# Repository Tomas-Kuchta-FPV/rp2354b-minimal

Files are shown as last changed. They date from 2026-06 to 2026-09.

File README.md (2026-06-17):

# RP2354B Minimal for KiCad 10

This is a realization of the Raspberry Pi RP2350 "Minimal" design.

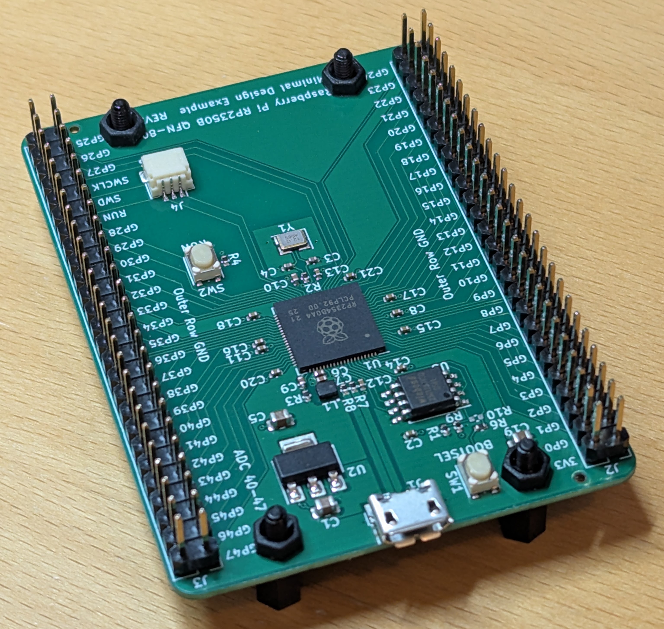
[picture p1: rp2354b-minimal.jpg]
Picture of Board


My main objectives were to try the RP2354 for the internal flash and use the
"B" part for the extra GPIOs.

Going through
[Hardware design with RP2350](https://pip-assets.raspberrypi.com/categories/1214-rp2350/documents/RP-008280-DS-1-hardware-design-with-rp2350.pdf)
is required to do this stuff and expect good results. It has a link to the
original Kicad 7.0 version.

Changes from the original example:

* Kicad 10.0.3 (was Kicad 7.0). This just means opening the project with
  10.0.3 and immediately saving it.

* RP2354 (was RP2350). This means changing some of the components from
  do-not-populate to populate, and vice versa.

* Added JLCPCB part numbers. There are lots of options for most parts, and I
  just picked ones in stock.

Then I created the manufacturing output for JLCPCB, uploaded the files, and a
week later got apparently-working boards. "Apparently" in that the board I've
tried shows up as a usb drive (Windows) if I hold BOOTSEL, the debugger
(Raspberry Pi debugger under VS Code) connects and can load code, the board
tells me it's running at 150 MHz, and I can blink LEDs after soldering on
headers. I have not tried using the secondary flash, just the internal flash.
The boards look nicely done, including getting the inductors turned the right
way on all five boards I got.

One objective was to change as little as possible, partly because I have not
done any boards with JLCPCB using 0402 and such tiny traces, and would be
unlikely to be able debug it if something didn't work, i.e. the oscillator or
power supply. But they must be fine.

I told VS Code it's a pico-2 to connect to it, so some stuff is probably wrong
(like flash size).

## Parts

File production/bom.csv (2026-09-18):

Designator | Footprint | Quantity | Value | LCSC Part #
C1, C19, C5 | 0805 | 3 | 10u | C15850
C10, C6, C7, C9 | 0402 | 4 | 4.7u | C368809
C11, C12, C13, C14, C15, C16, C17, C18, C2, C20, C21, C8 | 0402 | 12 | 100n | C16193311
C3, C4 | 0402 | 2 | 15p | C307341
J4 | JST_SH_SM03B-SRSS-TB_1x03-1MP_P1.00mm_Horizontal | 1 | SM03B-SRSS-TB | C160403
J5 | USB_C_Receptacle_HRO_TYPE-C-31-M-12 | 1 | USB_C_Receptacle_USB2.0_16P | C165948
L1 | L_pol_2016 | 1 | 3.3u | C42411119
R1 | 0402 | 1 | 10k | C25744
R12, R5 | 0805 | 2 | 5k1 | C84375
R2, R4, R6 | 0402 | 3 | 1k | C11702
R3 | 0402 | 1 | 33 | C25105
R7, R8 | 0402 | 2 | 27 | C138021
R9 | 0402 | 1 | 0 | C17168
SW1, SW2 | SW_Push_1P1T_NO_Vertical_Wuerth_434133025816 | 2 | SW_Push | C115360
U1 | RP2350-QFN-80-1EP_10x10_P0.4mm_EP3.4x3.4mm_ThermalVias | 1 | RP2350_80QFN | C39843328
U2 | SOT-223-3_TabPin2 | 1 | NCP1117-3.3_SOT223 | C26537
U3 | SOIC-8_5.23x5.23mm_P1.27mm | 1 | W25Q128JVS | C97521
U5 | SOT-23-6 | 1 | USBLC6-2SC6 | C2827654
Y1 | Crystal_SMD_3225-4Pin_3.2x2.5mm | 1 | ABM8-272-T3 | C20625731

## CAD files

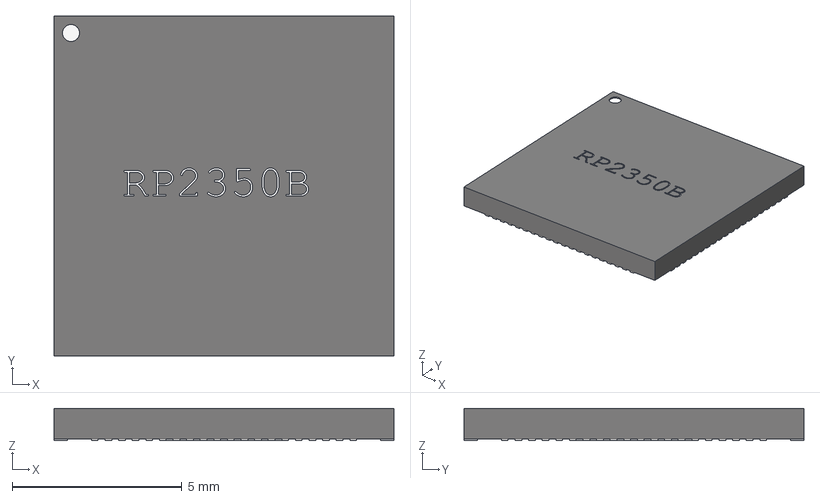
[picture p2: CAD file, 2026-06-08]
RP2350_QFN80.step
10.0 x 10.0 x 0.95 mm

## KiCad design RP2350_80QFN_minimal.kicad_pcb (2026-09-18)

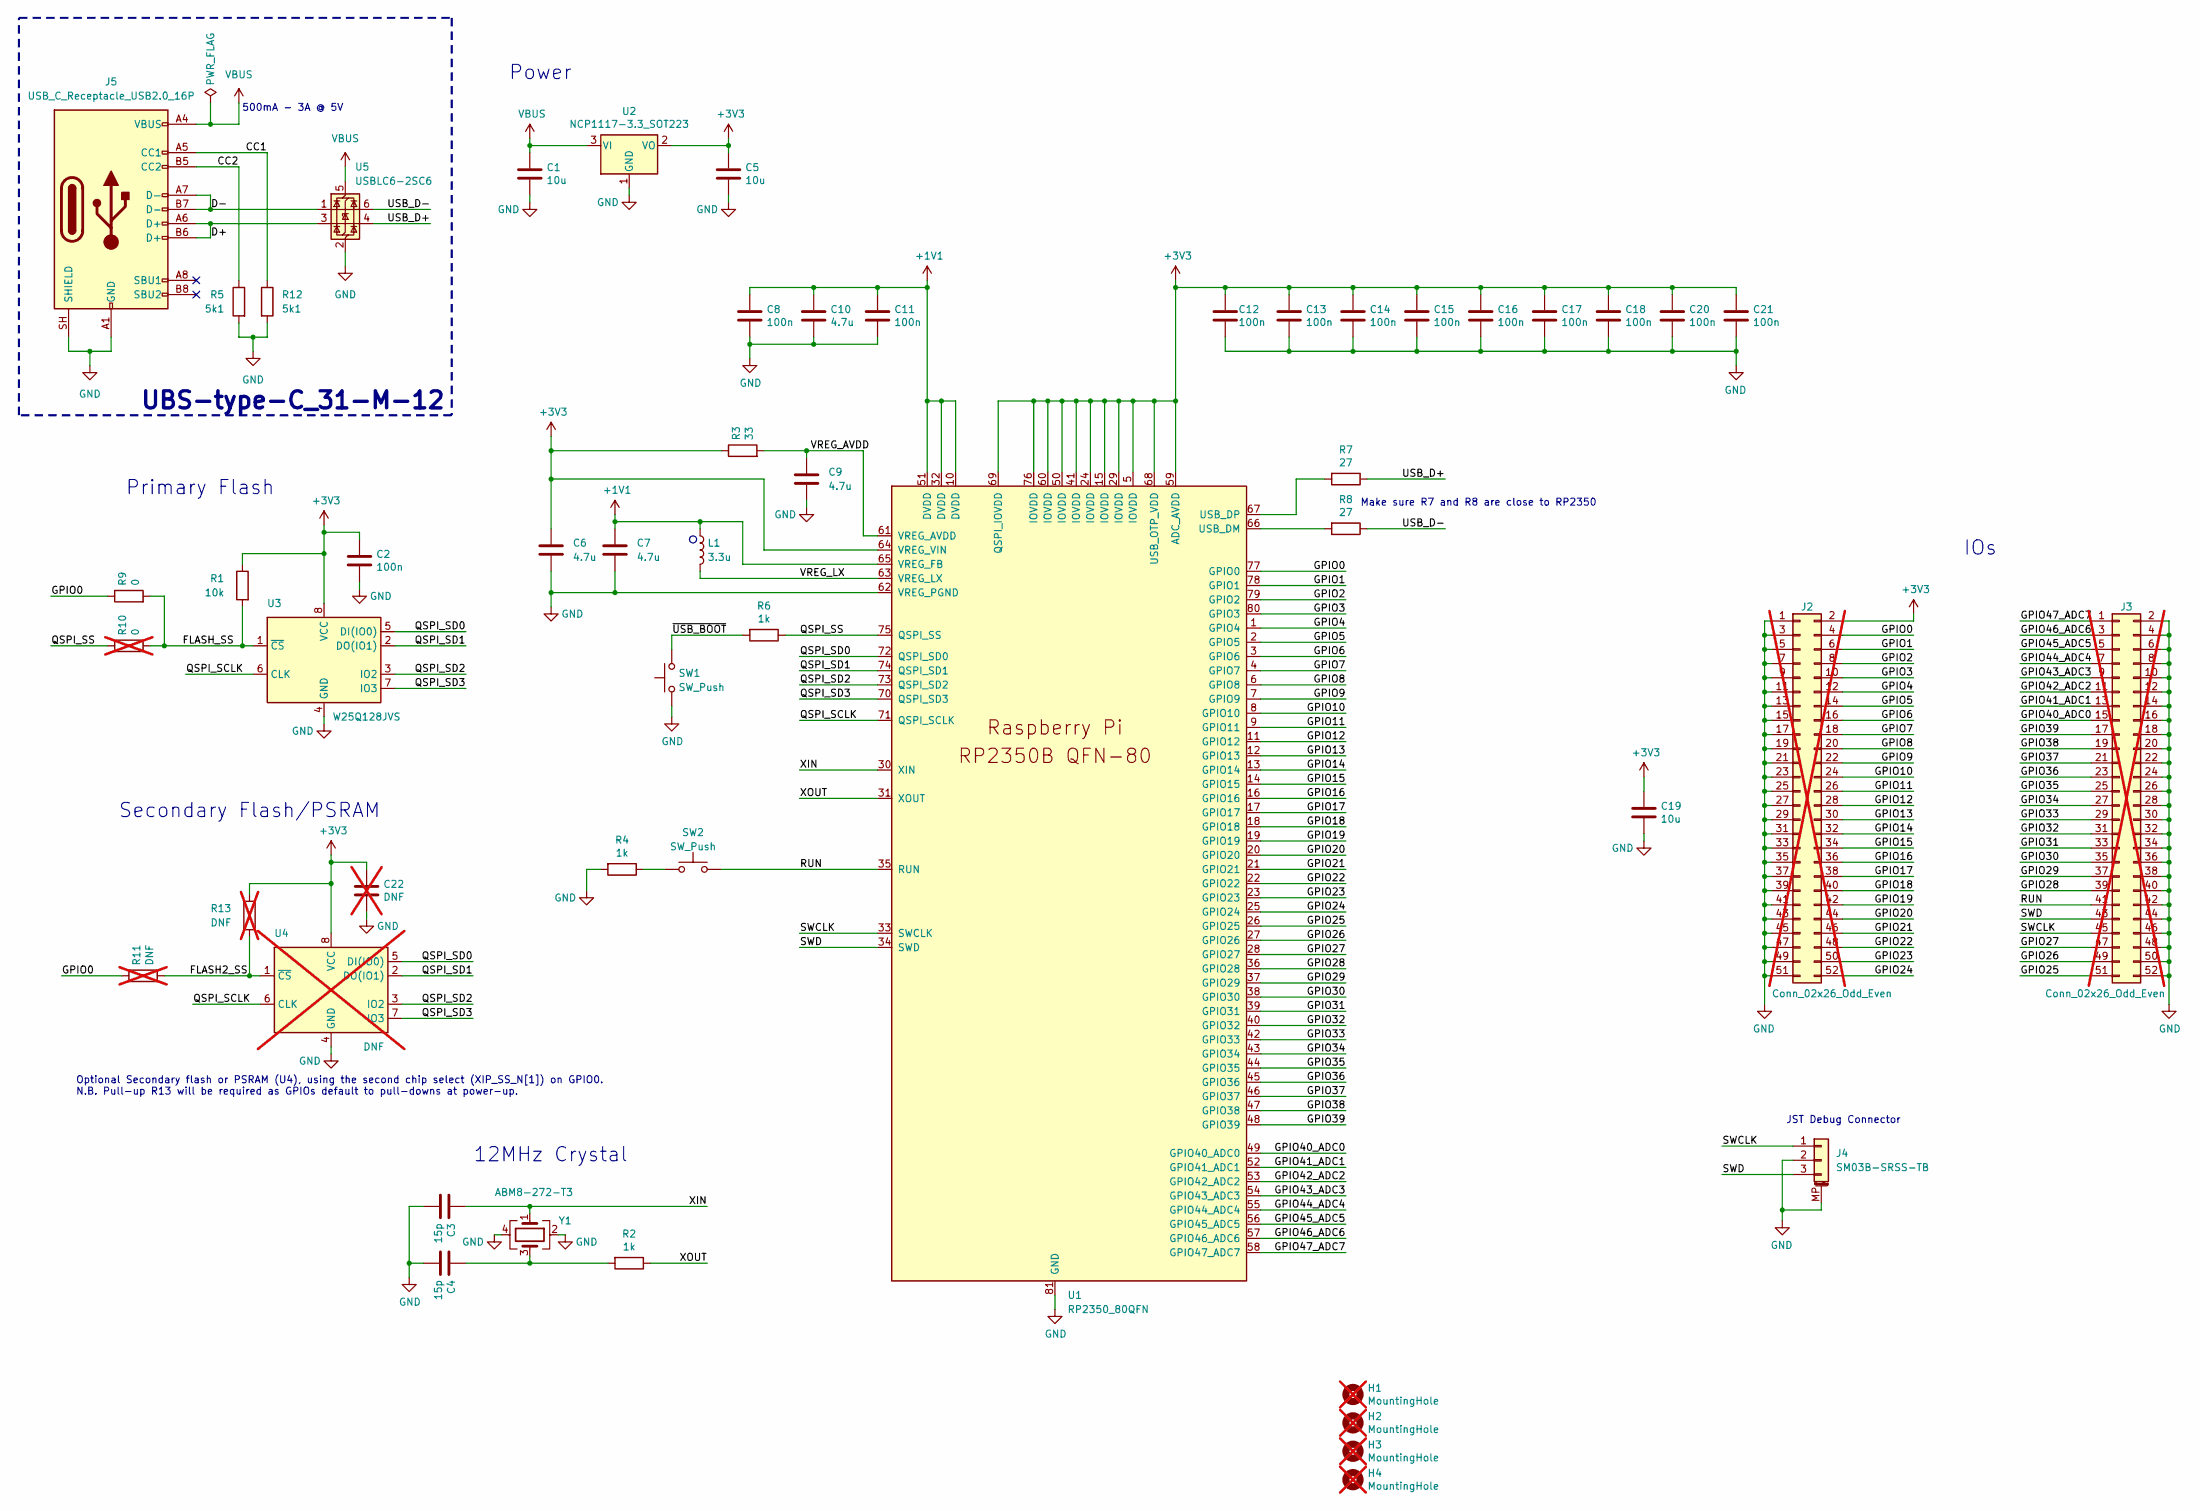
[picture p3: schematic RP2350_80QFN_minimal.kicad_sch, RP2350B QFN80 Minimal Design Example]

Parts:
C1, C5, C19: 10u; C_0805_2012Metric; LCSC PN C15850
C2, C8, C11, C12, C13, C14, C15, C16, C17, C18, C20, C21: 100n; C_0402_1005Metric; LCSC PN C16193311
C3, C4: 15p; C_0402_1005Metric; LCSC PN C307341
C6, C7: 4.7u; C_0402_1005Metric_small_pads; LCSC PN C368809
C9, C10: 4.7u; C_0402_1005Metric; LCSC PN C368809
C22: DNF; C_0402_1005Metric; not fitted
H1, H2, H3, H4: MountingHole; MountingHole_2.7mm_M2.5; not fitted
J2, J3: Conn_02x26_Odd_Even; PinHeader_2x26_P2.54mm_Vertical; not fitted
J4: SM03B-SRSS-TB; JST_SH_SM03B-SRSS-TB_1x03-1MP_P1.00mm_Horizontal; LCSC PN C160403
J5: USB_C_Receptacle_USB2.0_16P; USB_C_Receptacle_HRO_TYPE-C-31-M-12; LCSC C165948
L1: 3.3u; L_pol_2016; LCSC PN C42411119
R1: 10k; R_0402_1005Metric; LCSC PN C25744
R2, R4, R6: 1k; R_0402_1005Metric; LCSC PN C11702
R3: 33; R_0402_1005Metric; LCSC PN C25105
R5, R12: 5k1; R_0805_2012Metric_Pad1.20x1.40mm_HandSolder; LCSC C84375
R7, R8: 27; R_0402_1005Metric; LCSC PN C138021
R9: 0; R_0402_1005Metric; LCSC PN C17168
R10: 0; R_0402_1005Metric; not fitted
R11, R13: DNF; R_0402_1005Metric; not fitted
SW1, SW2: SW_Push; SW_Push_1P1T_NO_Vertical_Wuerth_434133025816; LCSC PN C115360
U1: RP2350_80QFN; RP2350-QFN-80-1EP_10x10_P0.4mm_EP3.4x3.4mm_ThermalVias; LCSC PN C39843328
U2: NCP1117-3.3_SOT223; SOT-223-3_TabPin2; LCSC PN C26537
U3: W25Q128JVS; SOIC-8_5.23x5.23mm_P1.27mm; LCSC PN C97521
U4: DNF; SOIC-8_5.23x5.23mm_P1.27mm; not fitted
U5: USBLC6-2SC6; SOT-23-6; LCSC C2827654
Y1: ABM8-272-T3; Crystal_SMD_3225-4Pin_3.2x2.5mm; LCSC PN C20625731

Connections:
+1V1: C7.1, C8.1, C10.1, C11.1, L1.1, U1.10 (DVDD), U1.32 (DVDD), U1.51 (DVDD), U1.65 (VREG_FB)
+3V3: C2.1, C5.1, C6.1, C12.1, C13.1, C14.1, C15.1, C16.1, C17.1, C18.1, C19.1, C20.1, C21.1, C22.1, J2.2, R1.1, R3.1, R13.1, U1.5 (IOVDD), U1.15 (IOVDD), U1.24 (IOVDD), U1.29 (IOVDD), U1.41 (IOVDD), U1.50 (IOVDD), U1.59 (ADC_AVDD), U1.60 (IOVDD), U1.64 (VREG_VIN), U1.68 (USB_OTP_VDD), U1.69 (QSPI_IOVDD), U1.76 (IOVDD), U2.2 (VO), U3.8 (VCC), U4.8 (VCC)
/CC1: J5.A5 (CC1), R12.1
/CC2: J5.B5 (CC2), R5.1
/D+: J5.A6 (D+), J5.B6 (D+), U5.3 (I/O2)
/D-: J5.A7 (D-), J5.B7 (D-), U5.1 (I/O1)
/FLASH2_SS: R11.2, R13.2, U4.1 (~CS)
/FLASH_SS: R1.2, R9.2, R10.2, U3.1 (~CS)
/GPIO0: J2.4, R9.1, R11.1, U1.77 (GPIO0)
/GPIO1: J2.6, U1.78 (GPIO1)
/GPIO2: J2.8, U1.79 (GPIO2)
/GPIO3: J2.10, U1.80 (GPIO3)
/GPIO4: J2.12, U1.1 (GPIO4)
/GPIO5: J2.14, U1.2 (GPIO5)
/GPIO6: J2.16, U1.3 (GPIO6)
/GPIO7: J2.18, U1.4 (GPIO7)
/GPIO8: J2.20, U1.6 (GPIO8)
/GPIO9: J2.22, U1.7 (GPIO9)
/GPIO10: J2.24, U1.8 (GPIO10)
/GPIO11: J2.26, U1.9 (GPIO11)
/GPIO12: J2.28, U1.11 (GPIO12)
/GPIO13: J2.30, U1.12 (GPIO13)
/GPIO14: J2.32, U1.13 (GPIO14)
/GPIO15: J2.34, U1.14 (GPIO15)
/GPIO16: J2.36, U1.16 (GPIO16)
/GPIO17: J2.38, U1.17 (GPIO17)
/GPIO18: J2.40, U1.18 (GPIO18)
/GPIO19: J2.42, U1.19 (GPIO19)
/GPIO20: J2.44, U1.20 (GPIO20)
/GPIO21: J2.46, U1.21 (GPIO21)
/GPIO22: J2.48, U1.22 (GPIO22)
/GPIO23: J2.50, U1.23 (GPIO23)
/GPIO24: J2.52, U1.25 (GPIO24)
/GPIO25: J3.51, U1.26 (GPIO25)
/GPIO26: J3.49, U1.27 (GPIO26)
/GPIO27: J3.47, U1.28 (GPIO27)
/GPIO28: J3.39, U1.36 (GPIO28)
/GPIO29: J3.37, U1.37 (GPIO29)
/GPIO30: J3.35, U1.38 (GPIO30)
/GPIO31: J3.33, U1.39 (GPIO31)
/GPIO32: J3.31, U1.40 (GPIO32)
/GPIO33: J3.29, U1.42 (GPIO33)
/GPIO34: J3.27, U1.43 (GPIO34)
/GPIO35: J3.25, U1.44 (GPIO35)
/GPIO36: J3.23, U1.45 (GPIO36)
/GPIO37: J3.21, U1.46 (GPIO37)
/GPIO38: J3.19, U1.47 (GPIO38)
/GPIO39: J3.17, U1.48 (GPIO39)
/GPIO40_ADC0: J3.15, U1.49 (GPIO40_ADC0)
/GPIO41_ADC1: J3.13, U1.52 (GPIO41_ADC1)
/GPIO42_ADC2: J3.11, U1.53 (GPIO42_ADC2)
/GPIO43_ADC3: J3.9, U1.54 (GPIO43_ADC3)
/GPIO44_ADC4: J3.7, U1.55 (GPIO44_ADC4)
/GPIO45_ADC5: J3.5, U1.56 (GPIO45_ADC5)
/GPIO46_ADC6: J3.3, U1.57 (GPIO46_ADC6)
/GPIO47_ADC7: J3.1, U1.58 (GPIO47_ADC7)
/QSPI_SCLK: U1.71 (QSPI_SCLK), U3.6 (CLK), U4.6 (CLK)
/QSPI_SD0: U1.72 (QSPI_SD0), U3.5 (DI(IO0)), U4.5 (DI(IO0))
/QSPI_SD1: U1.74 (QSPI_SD1), U3.2 (DO(IO1)), U4.2 (DO(IO1))
/QSPI_SD2: U1.73 (QSPI_SD2), U3.3 (IO2), U4.3 (IO2)
/QSPI_SD3: U1.70 (QSPI_SD3), U3.7 (IO3), U4.7 (IO3)
/QSPI_SS: R6.1, R10.1, U1.75 (QSPI_SS)
/RUN: J3.41, SW2.2, U1.35 (RUN)
/SWCLK: J3.45, J4.1, U1.33 (SWCLK)
/SWD: J3.43, J4.3, U1.34 (SWD)
/USB_D+: R7.1, U5.4 (I/O2)
/USB_D-: R8.1, U5.6 (I/O1)
/VREG_AVDD: C9.1, R3.2, U1.61 (VREG_AVDD)
/VREG_LX: L1.2, U1.63 (VREG_LX)
/XIN: C3.1, U1.30 (XIN), Y1.1
/XOUT: R2.1, U1.31 (XOUT)
/~USB_BOOT: R6.2, SW1.2
GND: C1.2, C2.2, C3.2, C4.2, C5.2, C6.2, C7.2, C8.2, C9.2, C10.2, C11.2, C12.2, C13.2, C14.2, C15.2, C16.2, C17.2, C18.2, C19.2, C20.2, C21.2, C22.2, J2.1, J2.3, J2.5, J2.7, J2.9, J2.11, J2.13, J2.15, J2.17, J2.19, J2.21, J2.23, J2.25, J2.27, J2.29, J2.31, J2.33, J2.35, J2.37, J2.39, J2.41, J2.43, J2.45, J2.47, J2.49, J2.51, J3.2, J3.4, J3.6, J3.8, J3.10, J3.12, J3.14, J3.16, J3.18, J3.20, J3.22, J3.24, J3.26, J3.28, J3.30, J3.32, J3.34, J3.36, J3.38, J3.40, J3.42, J3.44, J3.46, J3.48, J3.50, J3.52, J4.2, J4.MP (MountPin), J5.A1 (GND), J5.A12 (GND), J5.B1 (GND), J5.B12 (GND), J5.SH (SHIELD), R4.2, R5.2, R12.2, SW1.1, U1.62 (VREG_PGND), U1.81 (GND), U2.1 (GND), U3.4 (GND), U4.4 (GND), U5.2 (GND), Y1.2, Y1.4
unnamed: C4.1, R2.2, Y1.3
unnamed: R4.1, SW2.1
unnamed: R8.2, U1.66 (USB_DM)
unnamed: R7.2, U1.67 (USB_DP)
VBUS: C1.1, J5.A4 (VBUS), J5.A9 (VBUS), J5.B4 (VBUS), J5.B9 (VBUS), U2.3 (VI), U5.5 (VBUS)

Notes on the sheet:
Optional Secondary flash or PSRAM (U4), using the second chip select (XIP_SS_N[1]) on GPIO0. N.B. Pull-up R13 will be required as GPIOs default to pull-downs at power-up.
500mA - 3A @ 5V
IOs
12MHz Crystal
Primary Flash
JST Debug Connector
Make sure R7 and R8 are close to RP2350
Secondary Flash/PSRAM
Power
UBS-type-C_31-M-12

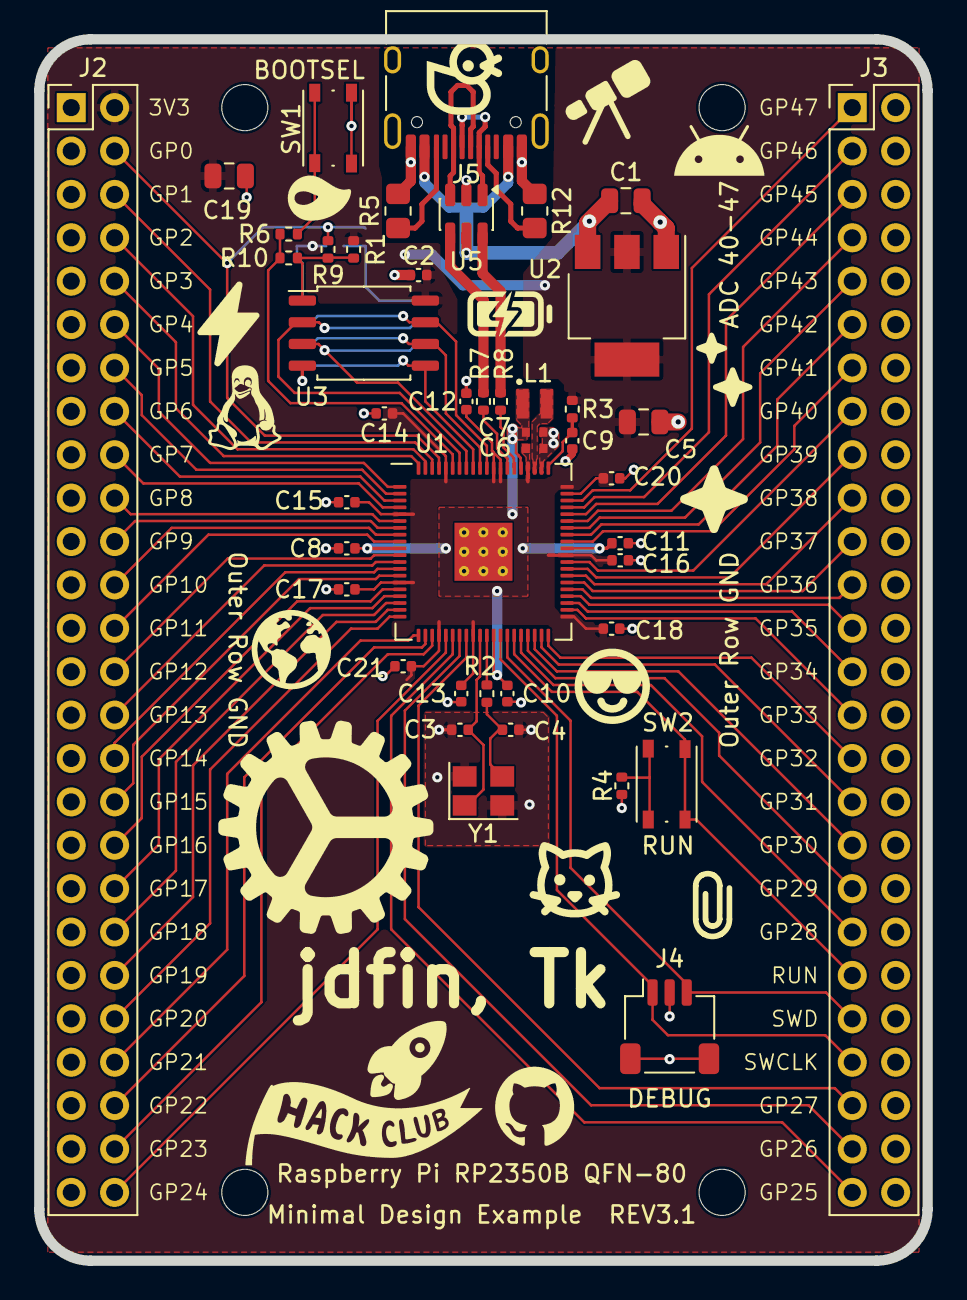
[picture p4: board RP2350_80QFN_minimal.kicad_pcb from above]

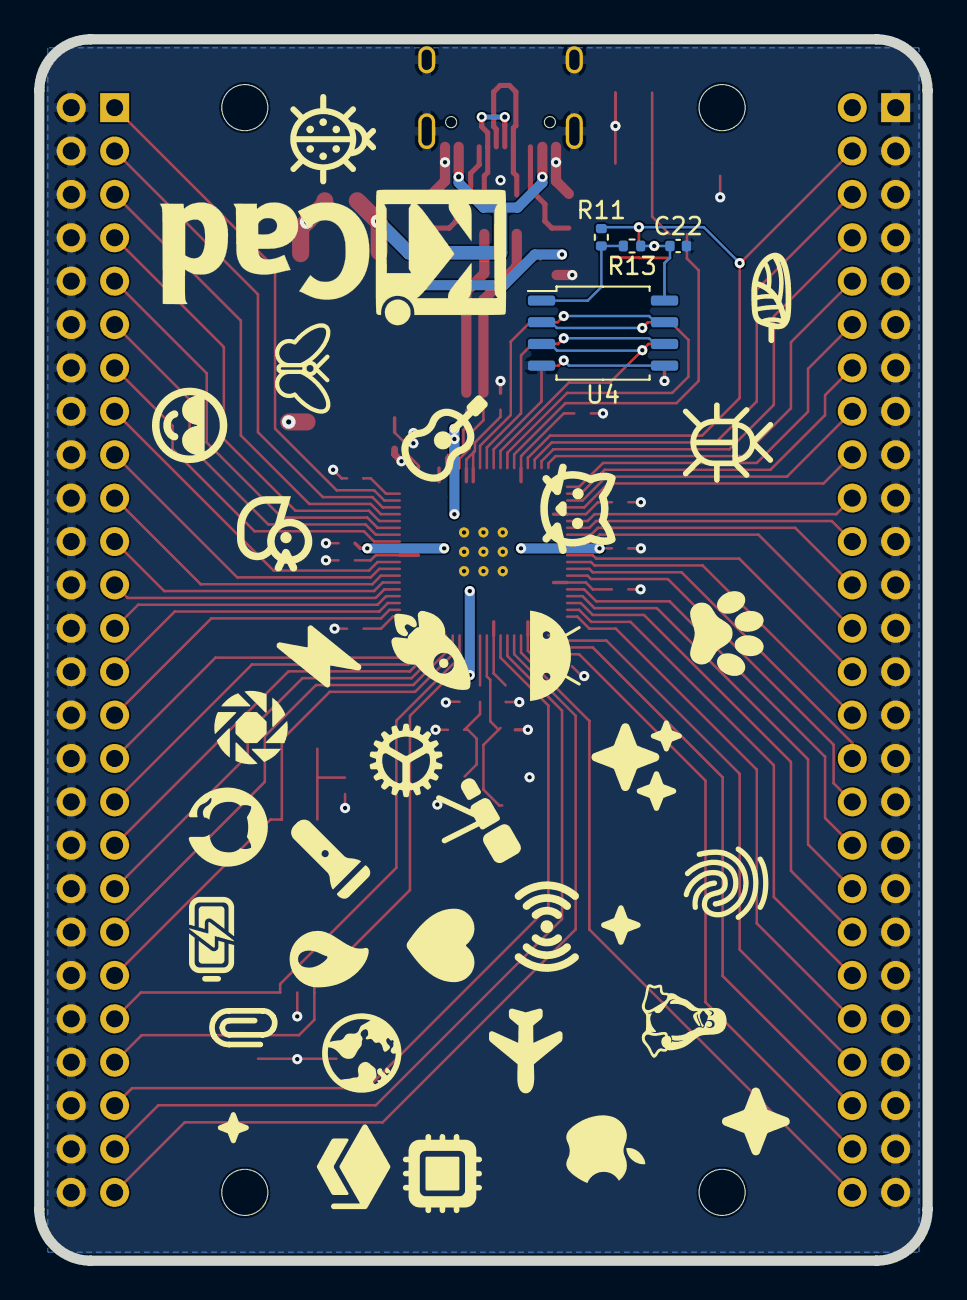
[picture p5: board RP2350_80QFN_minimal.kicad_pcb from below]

Board: 2 copper layers, 52.0 x 71.5 mm, 52 parts (4 on the bottom side), 78 nets.

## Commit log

2026-06-08 original version
    [RP2350_80QFN_minimal.kicad_pcb, RP2350_80QFN_minimal.kicad_sch, RP2350_80QFN_minimal.sch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]
2026-06-08 saved with kicad 10.0.3
    Opened and saved the schematic an pcb files.
    [RP2350_80QFN_minimal.kicad_pcb, RP2350_80QFN_minimal.kicad_sch]
2026-06-08 added jlcpcb part numbers, configured do-not-pop
    Primary flash is configured as secondary.
    Through-hole connectors not populated.
    [RP2350_80QFN_minimal.kicad_sch]
2026-06-09 as submitted to jlcpcb for manufacturing
    [RP2350_80QFN_minimal-B_Cu.gbl, RP2350_80QFN_minimal-B_Mask.gbs, RP2350_80QFN_minimal-B_Paste.gbp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]
2026-09-18 added USB-C to the board.
    [RP2350_80QFN_minimal.kicad_pcb, RP2350_80QFN_minimal.kicad_sch]
2026-09-18 added cool symbols!
    [RP2350_80QFN_minimal-B_Cu.gbl, RP2350_80QFN_minimal-B_Mask.gbs, RP2350_80QFN_minimal-B_Paste.gbp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]
